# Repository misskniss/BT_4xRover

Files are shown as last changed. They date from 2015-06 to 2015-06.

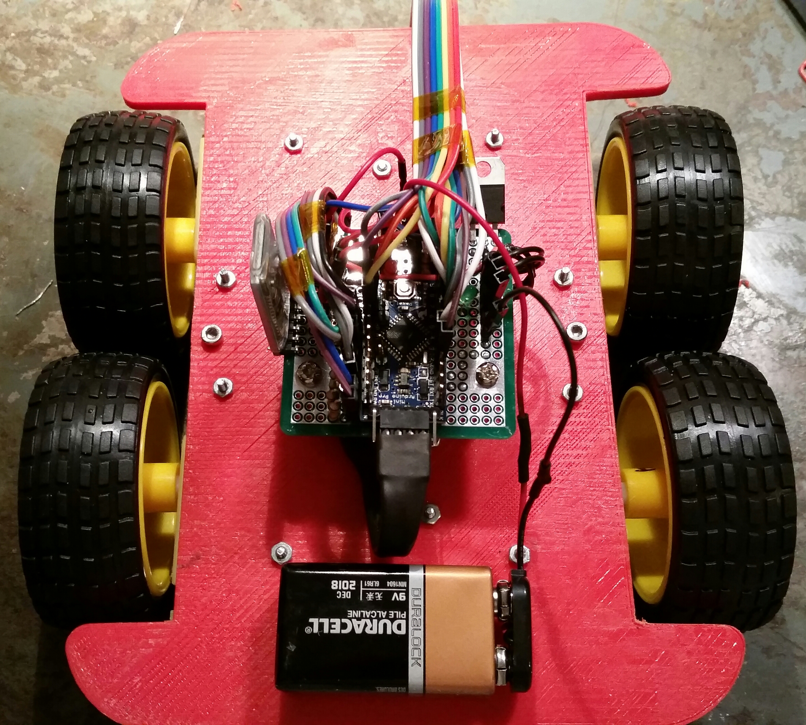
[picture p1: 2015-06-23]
BT_4xRover-TopView.jpg

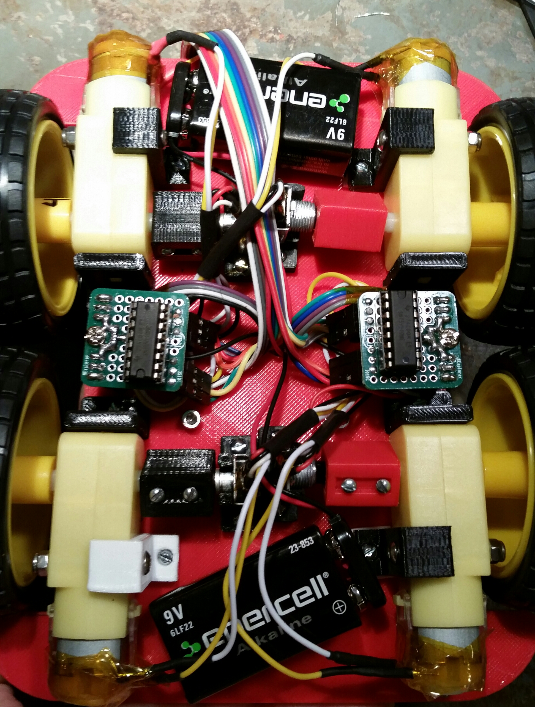
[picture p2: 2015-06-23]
BT_4xRover-MotorSide.jpg

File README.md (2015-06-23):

# BT_4xRover
4-Wheel Drive small Rover Bot. Bluetooth (HC-05) &amp; Acceleromter Controlled via Samsung Galaxy S5 Running SensoDuino App (Android 4.4.2). 

[Watch the video](https://drive.google.com/a/setek.io/file/d/0B9k3eDZYhuLoRUtQbXJCNnFkb2M/view) of the final product completeing a test course.

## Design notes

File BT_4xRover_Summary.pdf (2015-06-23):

Jenny Kniss
April 2015

BT_4xRover

A 4-Wheeled, Bluetooth controlled RC Car

FEATURES & NOTES

This RC Car is remote controlled using an HC-05 Bluetooth module connected to an Android phone.

The HC-05 module is attached to the main (top) circuit board, communicating between the BT_4xRover's Arduino Pro Mini UART and an Android phone running the SensoDuino Android App. The App reads and transmits the phones Accelerometer data which is then parsed and used to control
the BT_4xRover's heading (lf/rt), direction (fwd/rev) and speed.

Because the Arduino Pro Mini has 8 analog outputs, but only 6 of those can be used with a digital read, the navigation is not based on the encoders. Some modification would be required if PID control or additional fine-tuning is desired.

Schematic and Eagle board files are included here. I did not get the boards printed in time so the circuits in any images included here are manually soldered and split into 3 parts: 1 part for each h-bridge, 2 motors, and their encoders and one main/top part for the bluetooth, switches, GND, VCC, and Arduino.)

FILES

BT_4xRover_EagleFiles | (Eagle Board and Schematic)
BT_4xRover_SolidWorksFiles | (SolidWorks parts and full assembly file)
BT_4xRover_Code | (Software)
2 Images, one of the top and the under carriage of the BT_4xRover
COPYING | (License Info)

A video of the BT_4xRover completing a test course/demonstration can be viewed at:

https://drive.google.com/file/d/0B9k3eDZYhuLoRUtQbXJCNnFkb2M/view?usp=sharing (https://drive.google.com/file/d/0B9k3eDZYhuLoRUtQbXJCNnFkb2M/view?usp=sharing)

PARTS

Purchased:

DC Motor and wheel combo (x4) 9-Volt Motor power supply (x2) SN754410 H-Bridge (x2)
1" perf-board for circuit (x1) small DPDT switch (x1)
Rotary Encoders (x2)
Arduino Pro Mini (x1)
LM7805 Power Regulator for mini (x1) 9-Volt power supply for Mini (x1) small SPST switch (x1)
Misc posts, screws and wires

3D Printed:
Rotary encoder to Motor shaft hubs (x4) Chassis (x1)
Motor side mounts (x4)
Motor rear mounts (x4)
Encoder mounts (x4)

LICENSE INFO

See the COPYING file included with this project for the license details.

****************************************************************** **
Copyright 2015 Jenny Kniss

This file is part of BT_4xRover.

BT_4xRover is free software: you can redistribute it and/or modify
it under the terms of the GNU General Public License as published by
the Free Software Foundation, either version 3 of the License, or
(at your option) any later version.

BT_4xRover is distributed in the hope that it will be useful, but WITHOUT ANY WARRANTY; without even the implied warranty of MERCHANTABILITY or FITNESS FOR A PARTICULAR PURPOSE. See the GNU General Public License for more details.

You should have received a copy of the GNU General Public License
along with BT_4xRover. If not, see <http://www.gnu.org/licenses/>.

****************************************************************** **

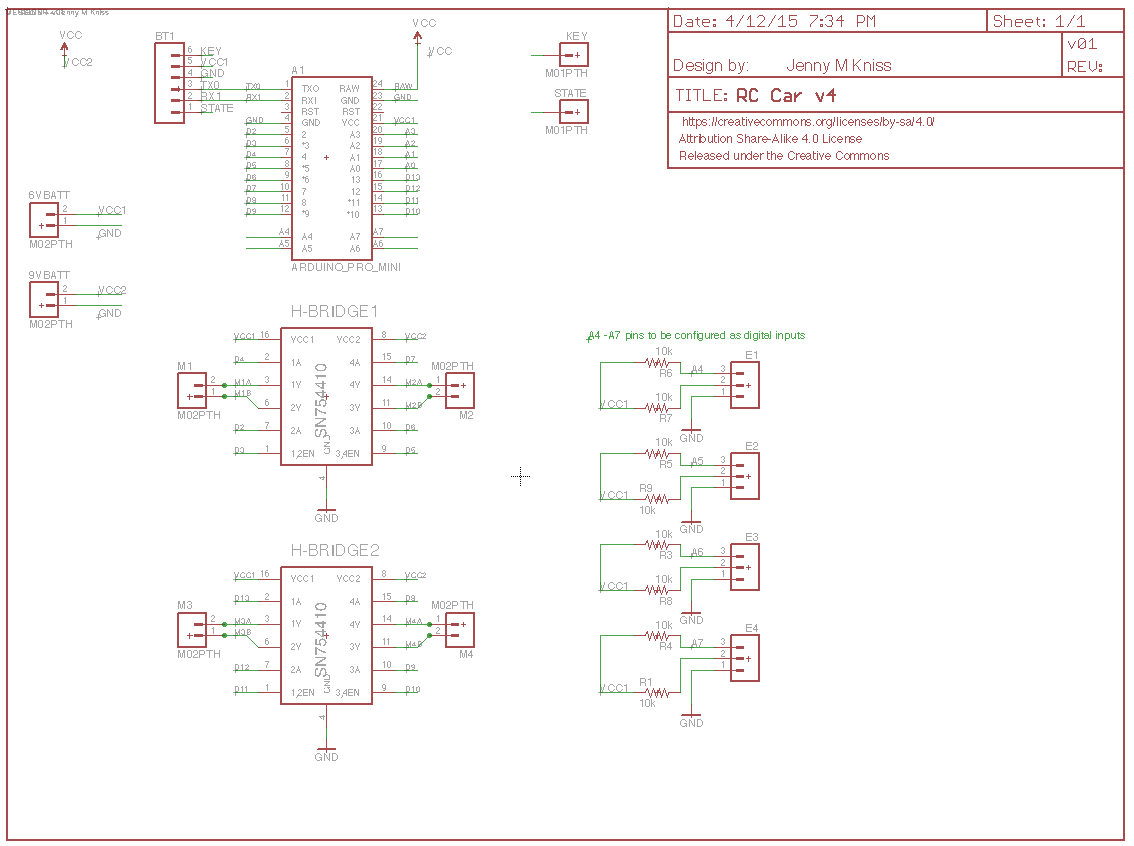
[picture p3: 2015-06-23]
BT_4xRover_EagleFiles/SchematicScreenShot.png

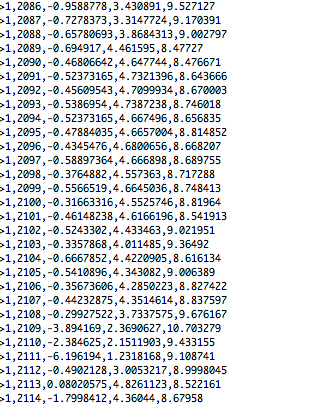
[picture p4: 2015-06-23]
BT_4xRover_Code/Example SensoDuino App Accelerometer Output.png

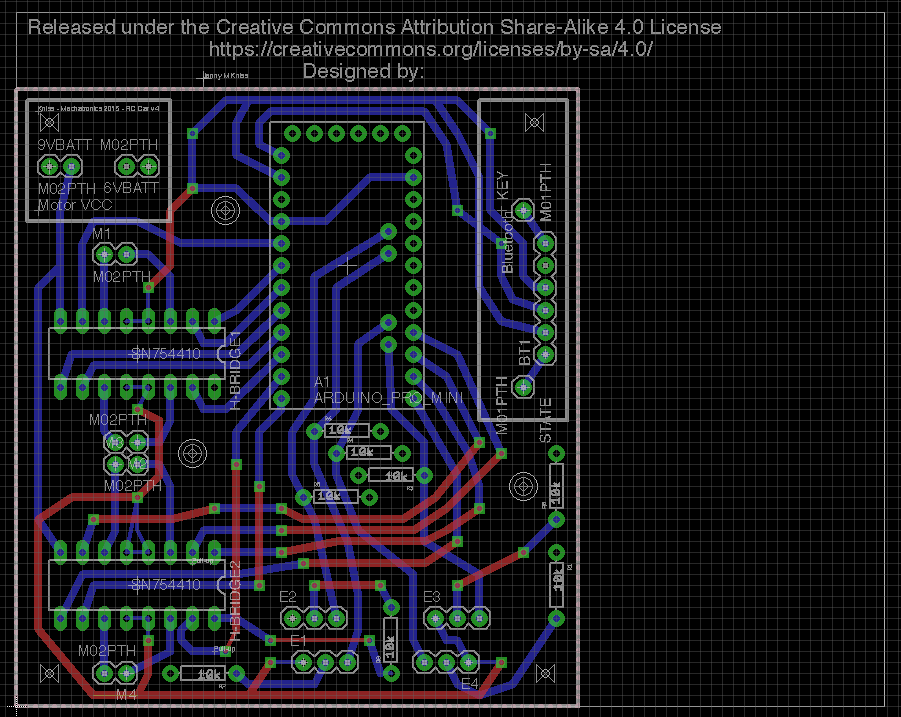
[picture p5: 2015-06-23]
BT_4xRover_EagleFiles/BoardScreenShot.png

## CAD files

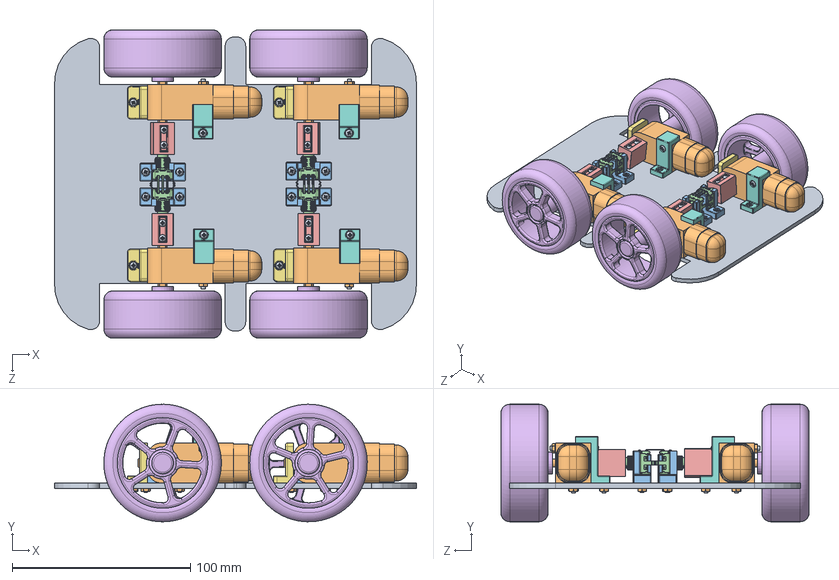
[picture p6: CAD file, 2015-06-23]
BT_4xRover_SolidWorksFiles/RC Car v2.SLDASM
203.2 x 66.0 x 173.1 mm
Chassis_v1
Motor_v1 x 4
EncoderMount x 4
Encoder x 4
Shaft-Encoder-Hub x 4
Wheel_v2 x 4
DCMotorMountRear x 4
DCMotorMountSide x 4
round head screw_ai x 28
machine screw nut hex_ai x 24

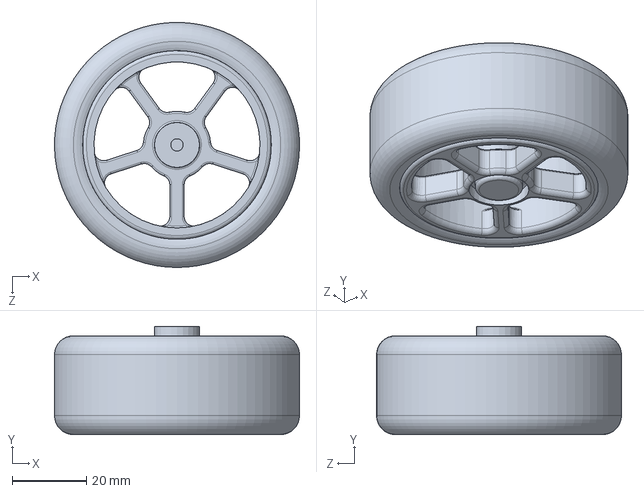
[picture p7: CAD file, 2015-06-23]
BT_4xRover_SolidWorksFiles/Wheel_v2.SLDPRT
66.0 x 29.1 x 66.0 mm

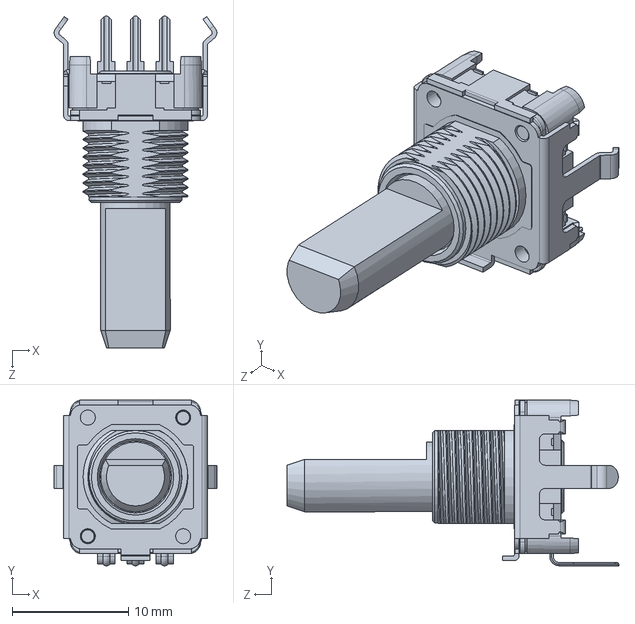
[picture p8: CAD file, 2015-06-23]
BT_4xRover_SolidWorksFiles/Encoder.SLDPRT
14.0 x 14.2 x 28.5 mm

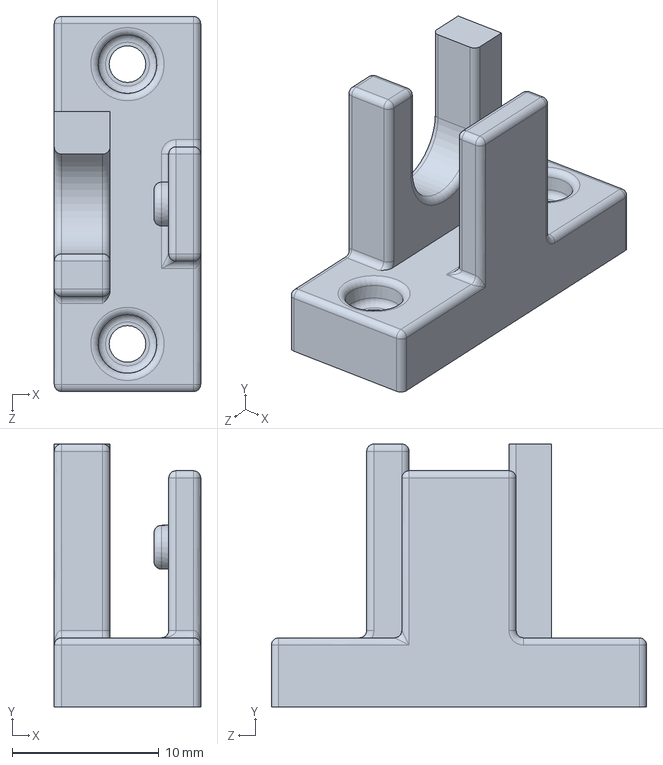
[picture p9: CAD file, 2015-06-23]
BT_4xRover_SolidWorksFiles/EncoderMount.SLDPRT
10.0 x 17.9 x 25.6 mm

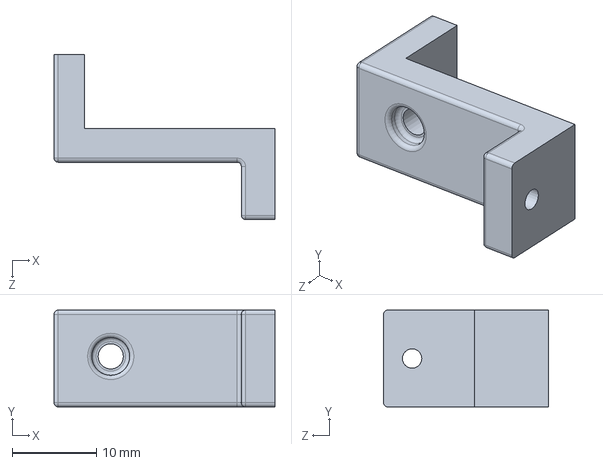
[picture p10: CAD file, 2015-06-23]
BT_4xRover_SolidWorksFiles/DCMotorMountSide.SLDPRT
26.2 x 11.5 x 19.6 mm

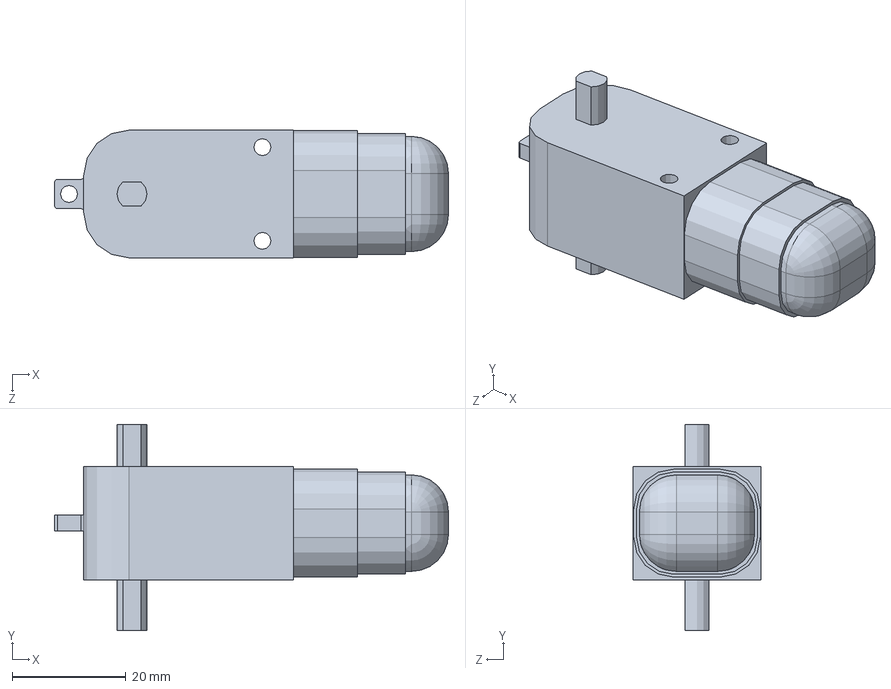
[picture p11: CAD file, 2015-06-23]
BT_4xRover_SolidWorksFiles/Motor_v1.SLDPRT
69.4 x 36.3 x 22.5 mm

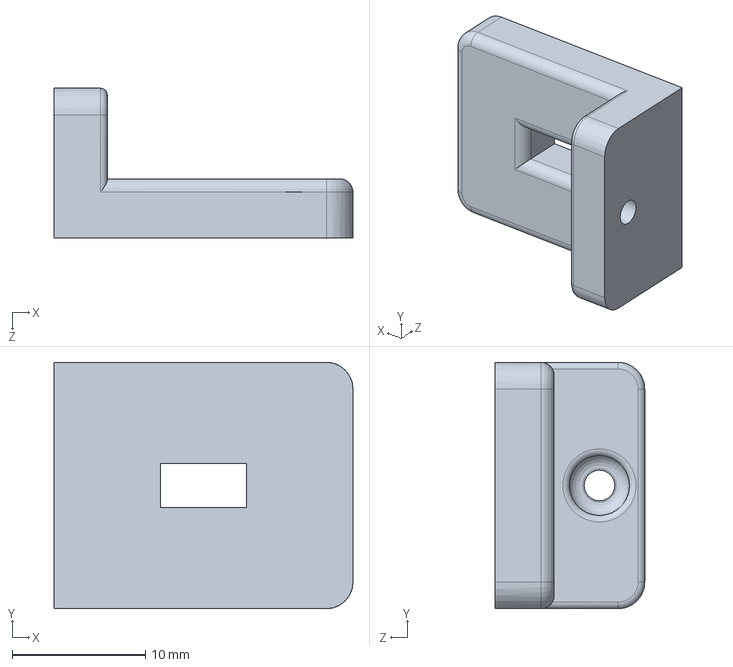
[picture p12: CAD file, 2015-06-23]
BT_4xRover_SolidWorksFiles/DCMotorMountRear.SLDPRT
22.5 x 18.5 x 11.2 mm

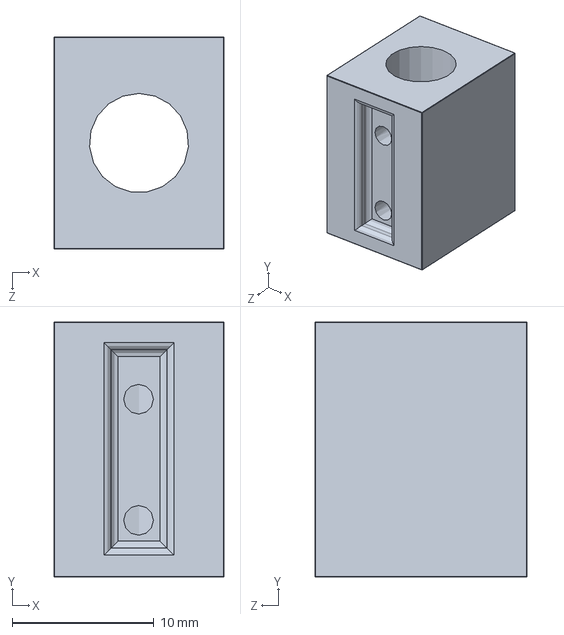
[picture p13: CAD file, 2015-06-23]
BT_4xRover_SolidWorksFiles/Shaft-Encoder-Hub.SLDPRT
12.0 x 18.0 x 15.0 mm

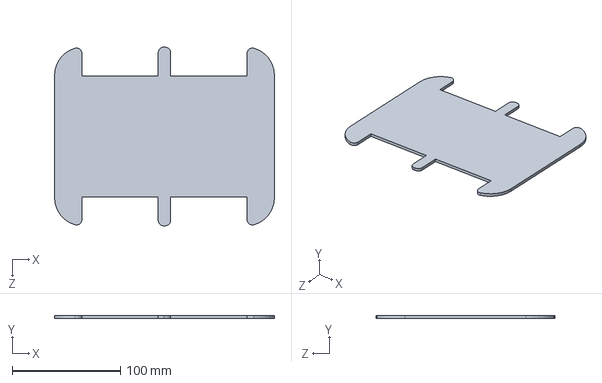
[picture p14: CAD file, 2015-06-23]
BT_4xRover_SolidWorksFiles/Chassis_v1.SLDPRT
203.2 x 3.00 x 165.1 mm

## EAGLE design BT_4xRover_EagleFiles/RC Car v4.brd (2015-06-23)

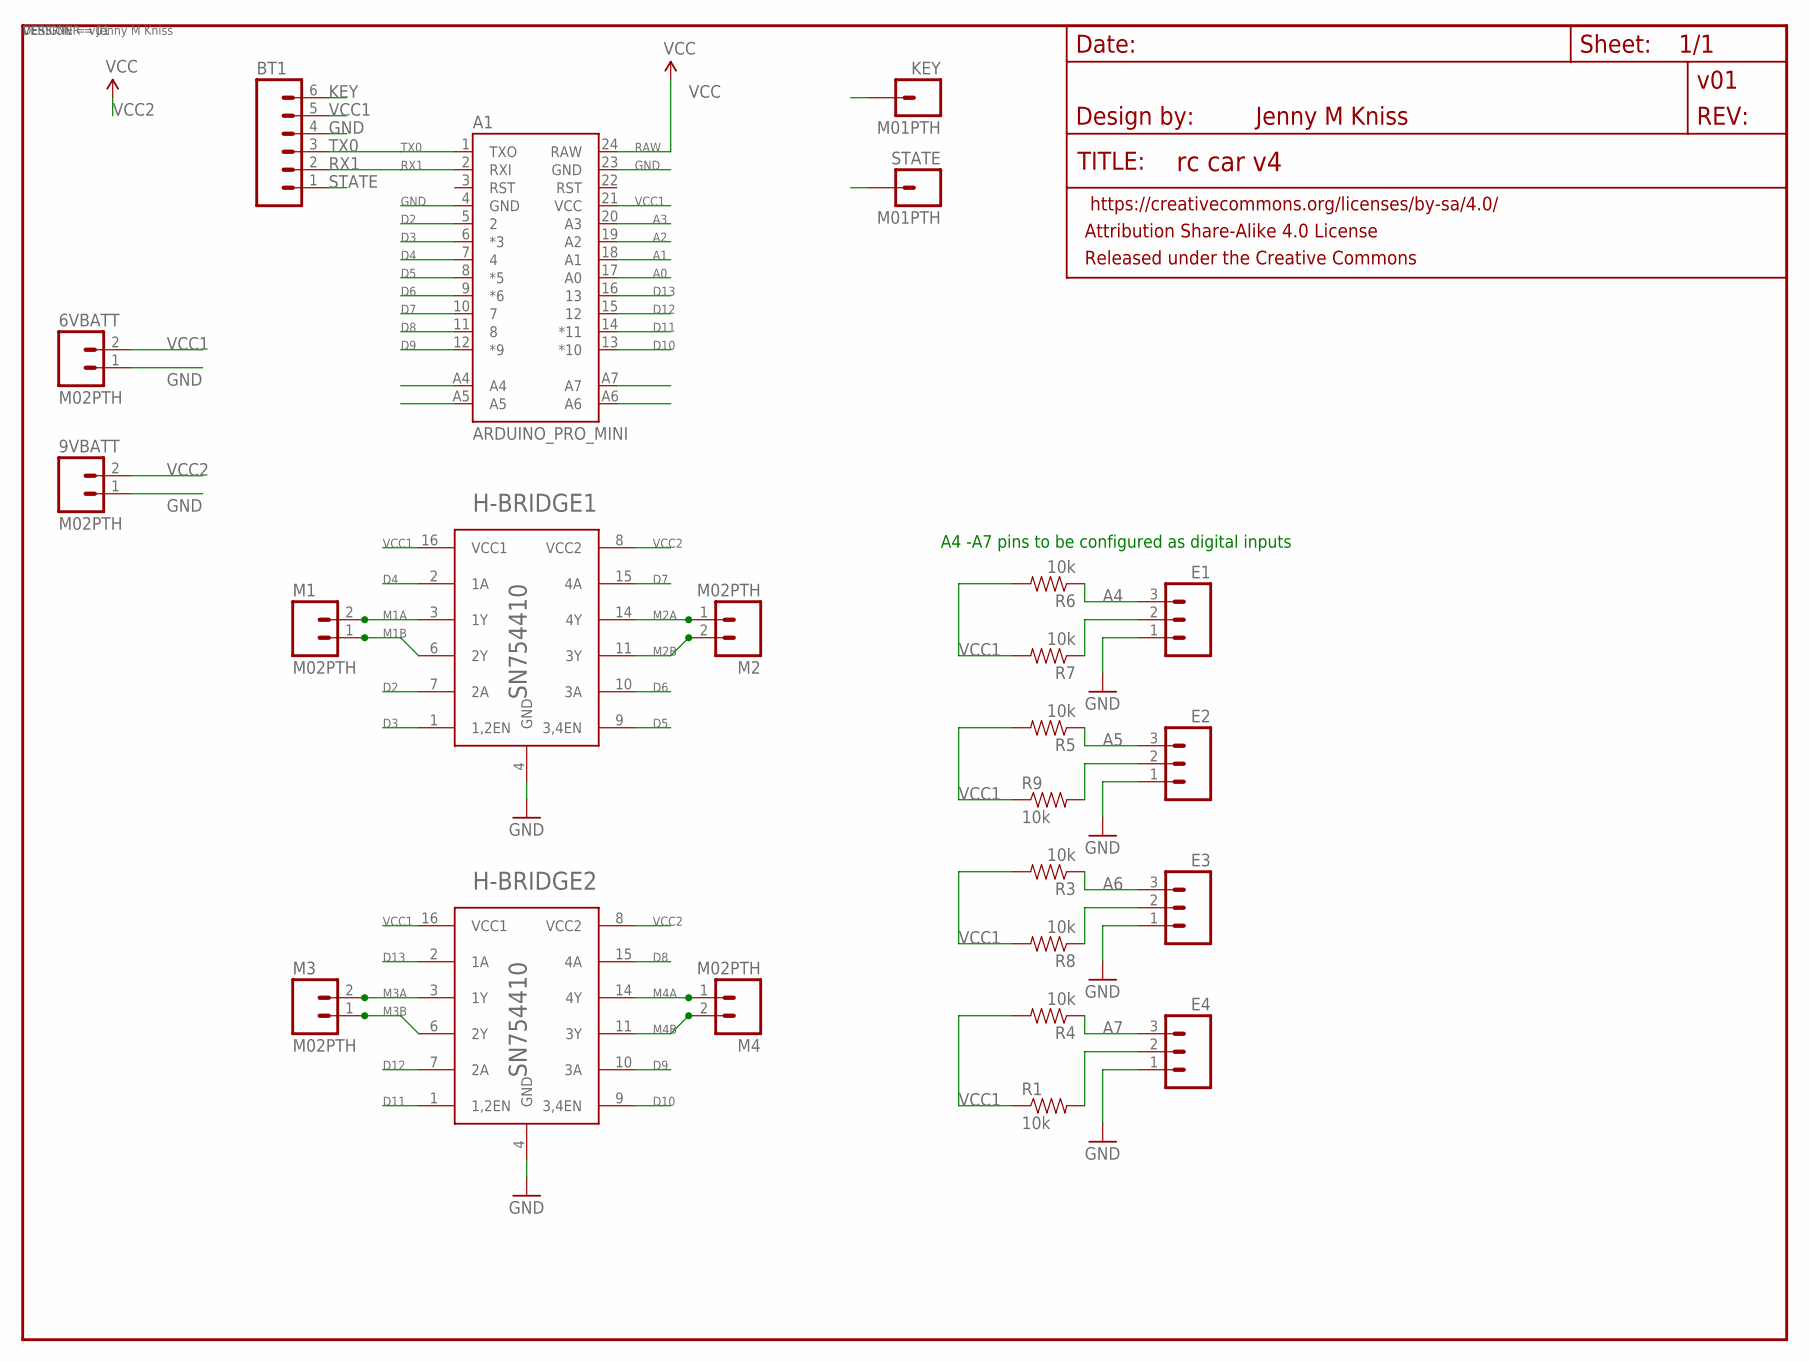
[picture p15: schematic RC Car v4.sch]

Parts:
6VBATT, 9VBATT: M02PTH; 1X02
A1: ARDUINO_PRO_MINI
BT1: M06SILK_FEMALE_PTH; 1X06
E1, E2, E3, E4: M03PTH; 1X03
H-BRIDGE1, H-BRIDGE2: SN754410; DIL16
KEY: M01PTH; 1X01
M1, M2, M3, M4: M02PTH; 1X02
R1, R3, R4, R5, R6, R7, R8, R9: 10k; AXIAL-0.3
RC_CAR: JENNY M KNISS; CREATIVE_COMMONS
STATE: M01PTH; 1X01

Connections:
A0: A1.17 (A0)
A1: A1.18 (A1)
A2: A1.19 (A2)
A3: A1.20 (A3)
A4: A1.A4, E1.3, R6.P$1 (1)
A5: A1.A5, E2.3, R5.P$1 (1)
A6: A1.A6, E3.3, R3.P$1 (1)
A7: A1.A7, E4.3, R4.P$1 (1)
D2: A1.5 (2), H-BRIDGE1.7 (2A)
D3: A1.6 (*3), H-BRIDGE1.1 (1,2EN)
D4: A1.7 (4), H-BRIDGE1.2 (1A)
D5: A1.8 (*5), H-BRIDGE1.9 (3,4EN)
D6: A1.9 (*6), H-BRIDGE1.10 (3A)
D7: A1.10 (7), H-BRIDGE1.15 (4A)
D8: A1.11 (8), H-BRIDGE2.15 (4A)
D9: A1.12 (*9), H-BRIDGE2.10 (3A)
D10: A1.13 (*10), H-BRIDGE2.9 (3,4EN)
D11: A1.14 (*11), H-BRIDGE2.1 (1,2EN)
D12: A1.15 (12), H-BRIDGE2.7 (2A)
D13: A1.16 (13), H-BRIDGE2.2 (1A)
GND: 6VBATT.1, 9VBATT.1, A1.4 (GND), A1.23 (GND), BT1.4, E1.1, E2.1, E3.1, E4.1, H-BRIDGE1.4 (GND), H-BRIDGE1.5 (GND), H-BRIDGE1.12 (GND), H-BRIDGE1.13 (GND), H-BRIDGE2.4 (GND), H-BRIDGE2.5 (GND), H-BRIDGE2.12 (GND), H-BRIDGE2.13 (GND)
KEY: BT1.6, KEY.1
M1A: H-BRIDGE1.3 (1Y), M1.2
M1B: H-BRIDGE1.6 (2Y), M1.1
M2A: H-BRIDGE1.14 (4Y), M2.1
M2B: H-BRIDGE1.11 (3Y), M2.2
M3A: H-BRIDGE2.3 (1Y), M3.2
M3B: H-BRIDGE2.6 (2Y), M3.1
M4A: H-BRIDGE2.14 (4Y), M4.1
M4B: H-BRIDGE2.11 (3Y), M4.2
unnamed: E2.2, R9.P$2 (2)
unnamed: E1.2, R7.P$1 (1)
unnamed: E3.2, R8.P$1 (1)
unnamed: E4.2, R1.P$2 (2)
RAW: A1.24 (RAW)
RX1: A1.2 (RXI), BT1.2
STATE: BT1.1, STATE.1
TX0: A1.1 (TXO), BT1.3
VCC1: 6VBATT.2, A1.21 (VCC), BT1.5, H-BRIDGE1.16 (VCC1), H-BRIDGE2.16 (VCC1), R1.P$1 (1), R3.P$2 (2), R4.P$2 (2), R5.P$2 (2), R6.P$2 (2), R7.P$2 (2), R8.P$2 (2), R9.P$1 (1)
VCC2: 9VBATT.2, H-BRIDGE1.8 (VCC2), H-BRIDGE2.8 (VCC2)

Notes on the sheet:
A4 -A7 pins to be configured as digital inputs

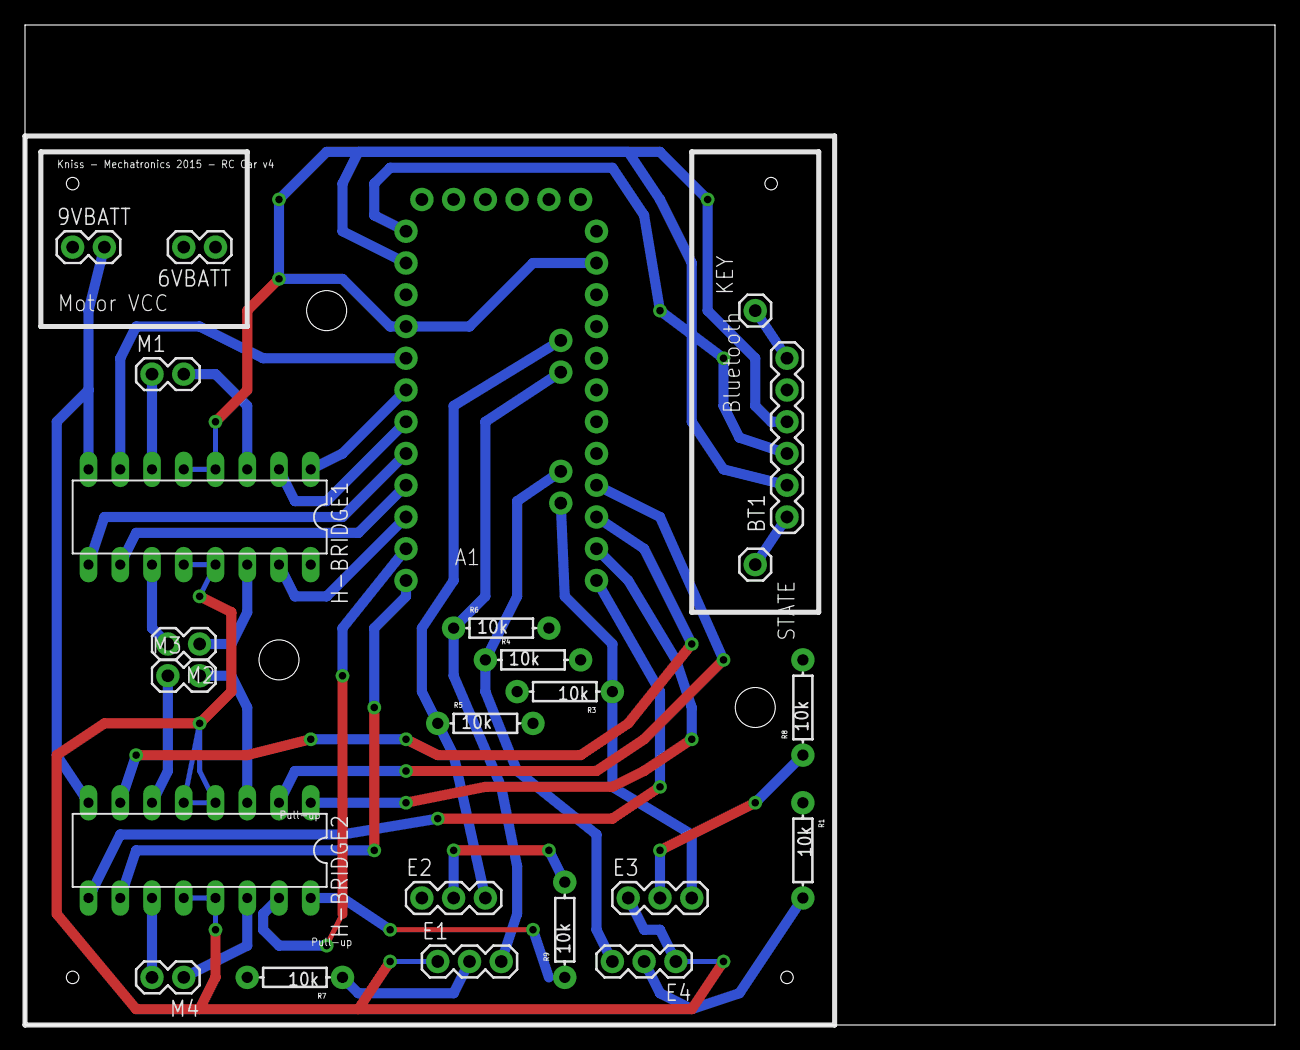
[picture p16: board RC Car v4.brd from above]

Board: 2 copper layers, 100.0 x 80.0 mm, 25 parts (0 on the bottom side), 35 nets.

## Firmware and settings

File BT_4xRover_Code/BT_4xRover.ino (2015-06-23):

/*

  File: BT_4xRover.ino
  Author: JKniss
  Date: April 2015

    ******************************************************************** 
    Copyright 2015 Jenny Kniss

    This file is part of BT_4xRover.

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

 Sensoduino Android Phone App -> HC-05 Bluetooth Module -> Arduino Pro Mini

 This module parses the data sent from the SensoDuino Android App, 
 (reading Accelerometer Sensor data from the phone) into 
 standard X, Y, Z whole number values from -10 to 10 for each axis. 
 These values are then mapped to the 0 - 255 PWM speed range for 
 PWM control of some device. (Minimum speed is 0 or 100)
 
 X values: 
            -1 to 1     stop
            -2 to -10   (increasingly) right
             2 to 10    (incrasingly) left
 Y values: 
            -1 to 1     stop
            -2 to -10    slowest to fastest
             2 to 10     reverse, slowest to fastest
 Z values:
            parsed but not used at this time 
            
 The SensoDuino app is v0.160 by Hazim Bitar (2013) from the 
 Android Play Store. My phone is the Galaxy S5, Android v4.4.2
*/

#include <Arduino.h>
#include <Drivetrain.h>

unsigned int startNum, readingCount;
int X, Y, Z;
unsigned int x_dec, y_dec, z_dec;
Drivetrain drive;

void setup() {
  Serial.begin(9600);
}

/* 
   Collect and parse the sensor data via the serial 
   connection/Bluetooth HC-05 module connected to the 
   phone app and transmitting to the Arduino Pro Mini
   Example reading: 
     startNum,readingCount,X,Y,Z
     >1,2086,-0.9588778,3.430891,9.527127
*/

void loop() {
  
  if(Serial.available() && Serial.read() == '>'){
    
    startNum = Serial.parseInt();
    readingCount = Serial.parseInt();
    X = Serial.parseInt();
    x_dec = Serial.parseInt(); // truncate the decimal
    Y = Serial.parseInt();
    y_dec = Serial.parseInt(); // truncate the decimal
    Z = Serial.parseInt();
    z_dec = Serial.parseInt();
    drive.update_speed(X, Y);
    
  } 
  
}

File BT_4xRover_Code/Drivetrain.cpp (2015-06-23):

/* 
   File: Drivetrain.cpp
   Author: Jkniss
   Date: April 2015
 
 ********************************************************************
 Copyright 2015 Jenny Kniss
 
 This file is part of BT_4xRover.
 
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
 
   This module creates a drivetrain instance with 4 motors (wheels)
   and sets motor speeds based on passed-in accelerometer X & Y values.
   The values are parsed to determine direction (fwd/rev), heading (rt/lt)
   and speeds. 
 
 */

#include <Arduino.h>
#include <DCMotor.h>
#include <Drivetrain.h>

bool FWD = true;
bool REV = false;

// create the new operator not supported by Arduino. Boo.
void* operator new(size_t size) { return malloc(size); }
void operator delete(void* ptr) { free(ptr); }

/* 
    Create an instance of the drive train with 4 motors
    that are precondifugrd with all the appropriate pinouts.
    Motor constructor for the SN754410 H-Bridge pins:
    Ex: DCMotor(motorNum, 1A Pin, 2A Pin, EnablePin)
*/
Drivetrain::Drivetrain(){
    
    frontLeft  = new DCMotor(1 , 4, 2,  3);
    frontRight = new DCMotor(2,  7, 8,  5);
    rearLeft   = new DCMotor(3, 10, 11, 6);
    rearRight  = new DCMotor(4, 13, 12, 9);
}


/*
   Used to slow the motor before changing the direction to avoid
   jolting.
*/
void Drivetrain::ramp_down( int spd, int dir ){
    /*
    int c; // might use this later...
    for(c = spd; c >= 0; c--){
      frontRight->set_speed(c, dir);
      rearRight->set_speed(c, dir);
      frontLeft->set_speed(c, dir);
      rearLeft->set_speed(c, dir);
     
    }
     */
    frontRight->disable();
    rearRight->disable();
    frontLeft->disable();
    rearLeft->disable();
}


/*
    Maintain the left wheels' speed and slow the right
    wheels in proportion to the "master speed" setting.
    Smaller spd values = wider turns.
*/
void Drivetrain::turn_right( int spd ){
    
    _leftWheels = _speedVal;
    _rightWheels = _speedVal - (_increment*spd); 
    
    
    frontRight->set_speed(_rightWheels, _DIR);
    rearRight->set_speed(_rightWheels, _DIR);
    frontLeft->set_speed(_leftWheels, _DIR);
    rearLeft->set_speed(_leftWheels, _DIR);
    
}


/* 
    Maintain the right wheels' speed and slow the left
    wheels in proportion to the "master speed" setting.
    Smaller spd values = wider turns.
*/
void Drivetrain::turn_left( int spd ){
    
    _rightWheels = _speedVal;
    _leftWheels = _speedVal - (_increment*spd);
    
    frontRight->set_speed(_rightWheels, _DIR);
    rearRight->set_speed(_rightWheels, _DIR);
    frontLeft->set_speed(_leftWheels, _DIR);
    rearLeft->set_speed(_leftWheels, _DIR);
    
}


/*
    Map master speed (100 - 255) to passed in abs values from 2 - 10.
    Calculation of the increment/decrement value for turning done here.
    Values of 0 or 1 set the speed to zero and are not handled here.
*/
void Drivetrain::set_speed_val( int spd ){
    switch (spd){
        case 2:
            _speedVal = 100;
            break;
        case 3:
            _speedVal = 122;
            break;
        case 4:
            _speedVal = 144;
            break;
        case 5:
            _speedVal = 166;
            break;
        case 6:
            _speedVal = 188;
            break;
        case 7:
            _speedVal = 210;
            break;
        case 8:
            _speedVal = 232;
            break;
        case 9:
            _speedVal = 250;
            break;
        case 10:
            _speedVal = 250;
            break;
        default:
            _speedVal = 0;
            
    }
    
    /* Pre-Calculate the incr value. */
    _increment = (_speedVal/10);
    Serial.print("Master Speed: ");
    Serial.println(_speedVal);
    Serial.print("Increment: ");
    Serial.println(_increment);
    
}

int Drivetrain::get_speed_val( void ){
    return _speedVal;
}


/* 
    Set the direction.
    0: reverse
    1: forward
 */
void Drivetrain::set_direction( bool dir ){
	_DIR = dir;
    //Serial.print("Direction: ");
    //Serial.println(_DIR);
}

int Drivetrain::get_direction( void ){
    return _DIR;
}

/*
    Use the passed in X and Y values to set master speed and
    and determine if we are going left (x >= 2) or right (x <= -2), 
    and forward (y <= -2) or back (y >= 2). If both X and Y are
    between -1 and 1 (phone laying flat & face up) the stop the rover.
*/
void Drivetrain::update_speed(int x, int y){
    
    // if y and x are between -1 and 1, stop
    if ( y <= 1 && y >= -1 ){
        if (x <= 1 && x>= -1){
            set_speed_val(0);
            // full stop
            frontLeft->disable();
            frontRight->disable();
            rearLeft->disable();
            rearRight->disable();
        }
        
        // x dictates speed when y is -1 to 0
        if (x >= 2){
            set_speed_val( x );
            turn_left( x );
        }
        if (x <= -2){
            set_speed_val( abs(x) );
            turn_right( abs(x) );
        }
    }
    
    // REVERSE with Turning
    if (y >= 2){
        
        // check & set direction
        int direction = get_direction();
        if(direction == FWD){
            ramp_down( get_speed_val(), direction );
            set_direction( REV );
        }
      
        set_speed_val( y );
        
        if( x >= 2 ){
            turn_left( _speedVal );
            //turn_left( get_speed_val() );
        }
        if(x <= -2 ){
            turn_right( _speedVal );
            //turn_right( get_speed_val() );
        }
        
        frontLeft->set_speed(_speedVal, _DIR);
        frontRight->set_speed(_speedVal, _DIR);
        rearLeft->set_speed(_speedVal, _DIR);
        rearRight->set_speed(_speedVal, _DIR);
        
    }
    
    // FORWARD with Turning
    if ( y <= -2){
        
        // check & set direction
        int direction = get_direction();
        if(direction == REV){
            ramp_down( get_speed_val(), direction );
            set_direction( FWD );
        }
        
        set_speed_val( abs(y) );
        
        if( x >= 2 ){
            turn_left( _speedVal );
        }
        if(x <= -2 ){
            turn_right( _speedVal );
        }
        
        frontLeft->set_speed(_speedVal, _DIR);
        frontRight->set_speed(_speedVal, _DIR);
        rearLeft->set_speed(_speedVal, _DIR);
        rearRight->set_speed(_speedVal, _DIR);

    }
    
    Serial.print("X: ");
    Serial.println(x);
    Serial.print("Y: ");
    Serial.println(y);


}

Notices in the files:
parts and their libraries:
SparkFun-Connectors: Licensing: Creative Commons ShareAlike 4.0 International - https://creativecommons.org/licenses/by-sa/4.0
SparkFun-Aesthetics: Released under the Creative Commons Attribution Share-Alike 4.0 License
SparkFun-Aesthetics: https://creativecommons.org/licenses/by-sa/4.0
